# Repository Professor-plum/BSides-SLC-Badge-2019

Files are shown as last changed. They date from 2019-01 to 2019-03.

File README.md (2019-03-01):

# BSides-SLC-Badge-2019
source code, design files and artwork used in the BSides SLC 2019 badge

The following libraries were utilized in this project

https://github.com/rogerclarkmelbourne/Arduino_STM32
https://github.com/PaulStoffregen/SerialFlash
https://github.com/PaulStoffregen/XPT2046_Touchscreen

After installing these libraries, one edit needs to be made:

```
vim ~/Documents/Arduino/libraries/SerialFlash/SerialFlashChip.cpp
```

On line 161, change `SPIPORT.transfer(p, rdlen);` to be `SPIPORT.read(p, rdlen);`. I'm not sure if this is a bug in SerialFlash, or if SerialFlash was just designed to use a different STM32 library.

Now, in the Arduino IDE, you can open `src/BsidesSLCBig/BsidesSLCBig.ino`. Compile using the following board settings:

```
Board: "Generic STM32F103C Series"
Variant: "STM32F103CB (20k RAM, 128k Flash)"
```

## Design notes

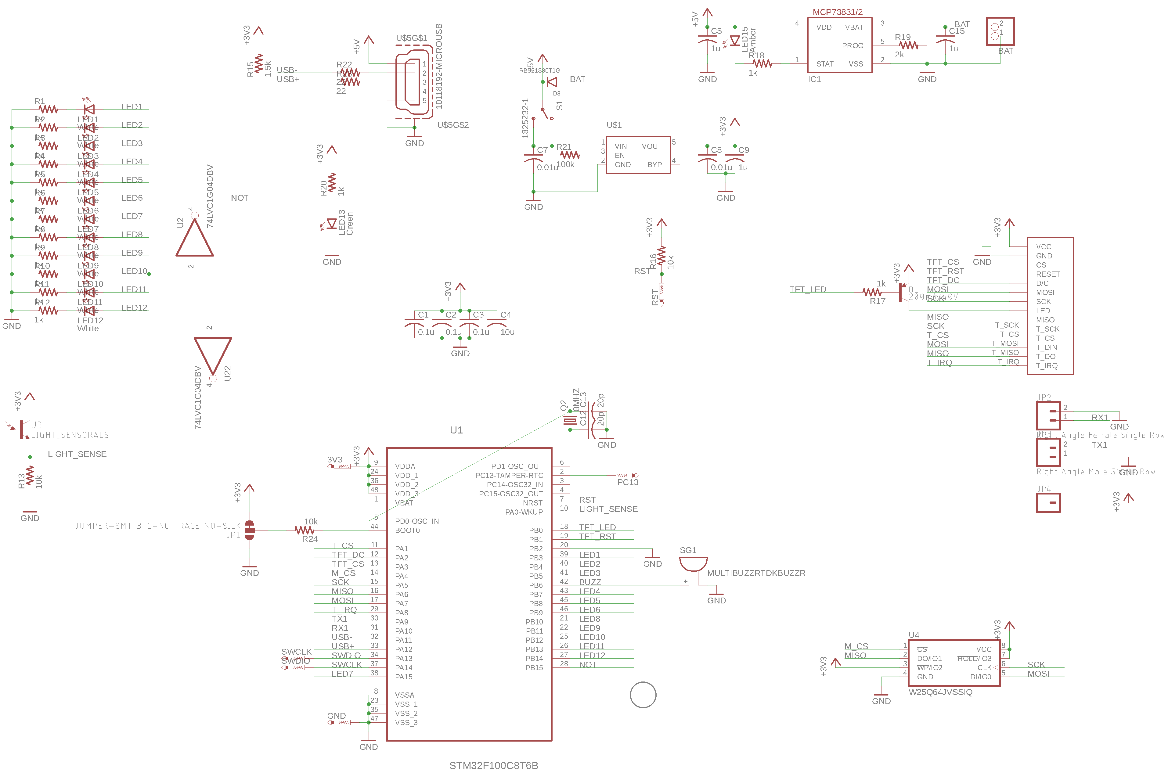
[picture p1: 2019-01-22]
eagle/Schematic.png

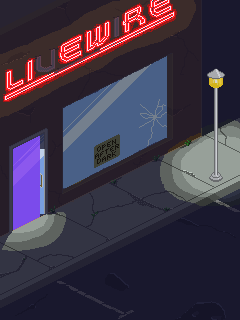
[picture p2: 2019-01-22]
img/nclub2.bmp

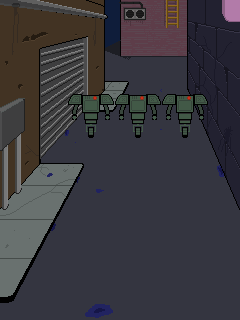
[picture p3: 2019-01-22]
img/street1.bmp

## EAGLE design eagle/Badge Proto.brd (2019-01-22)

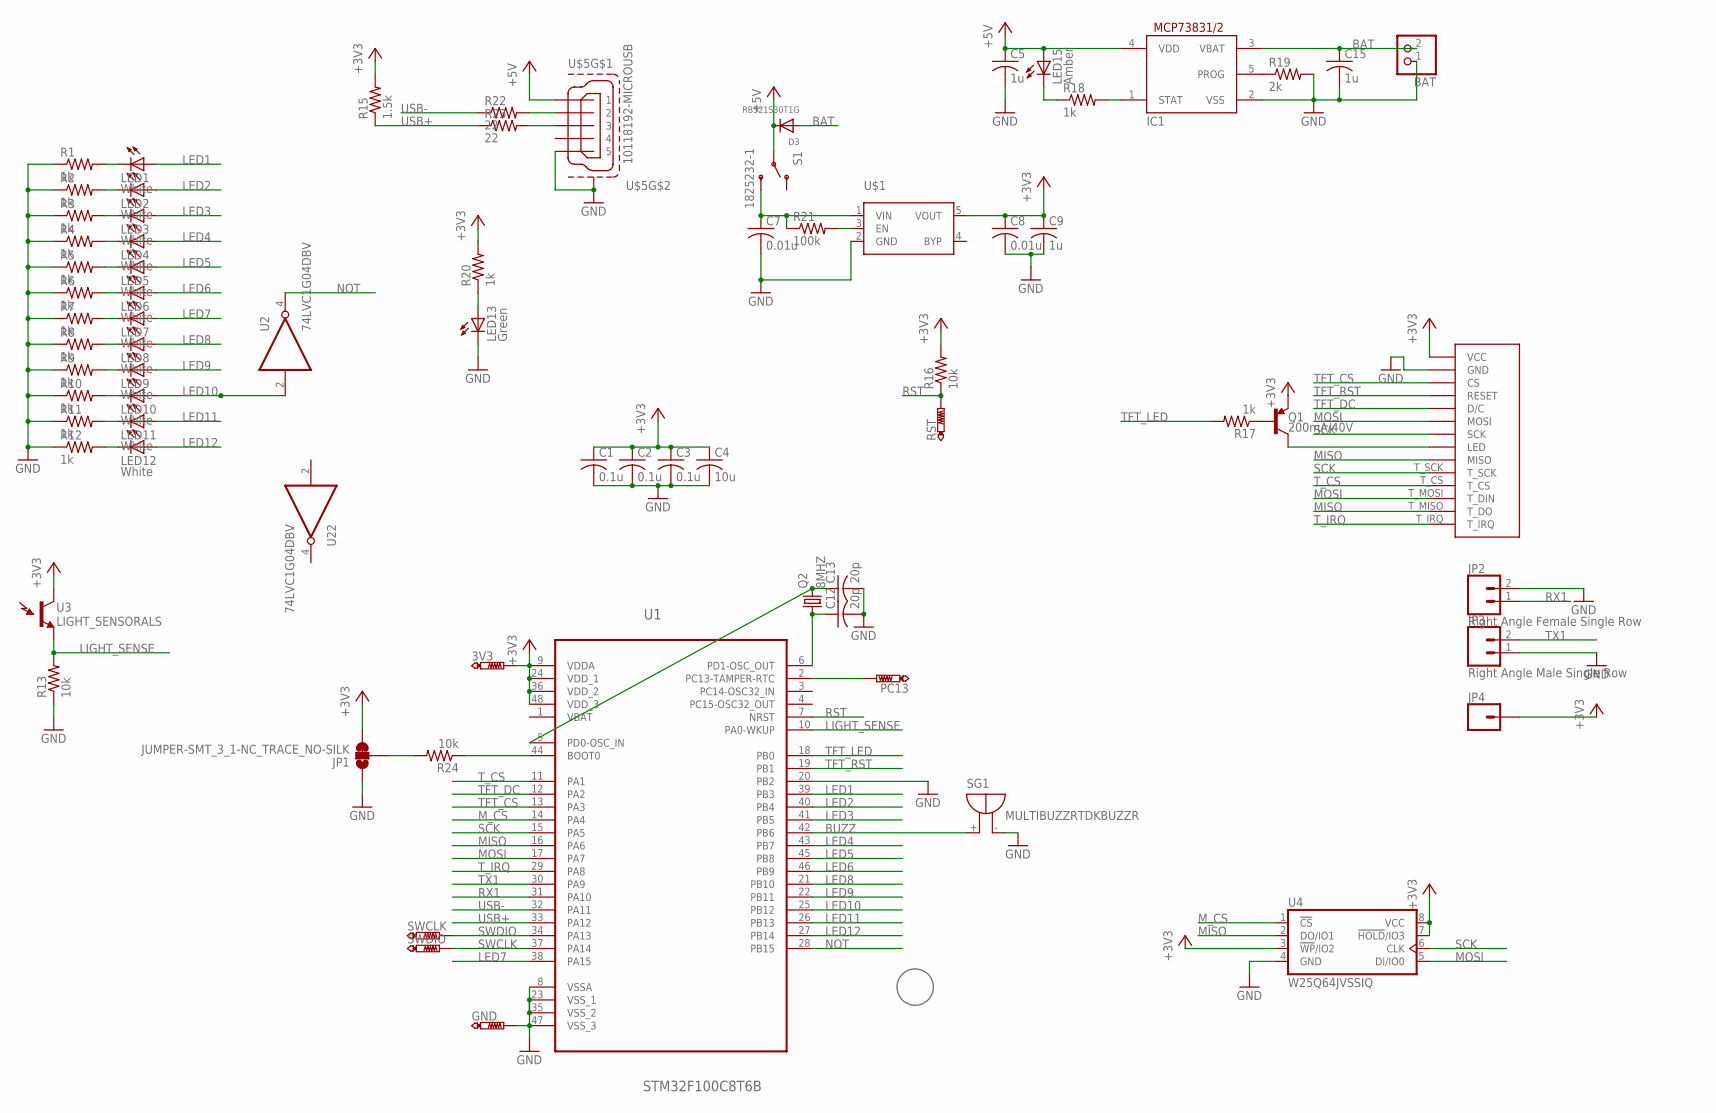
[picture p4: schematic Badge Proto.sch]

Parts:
3V3: PTR1TP15R; TP15R
BAT: JST_2PIN-THM-RA; JST-PH-2-THM-RA
C1, C2, C3: 0.1u; C0603K; MPN MC0603B104K160CT
C4: 10u; C0603K; MPN C1608X5R1A106K080AC
C5, C9, C15: 1u; C0603K; MPN C0603C104K8RACTU
C7, C8: 0.01u; C0603K
C12, C13: 20p; C0603K
D3: RB521S30T1G; SOD-523; MPN 1N4148WT.
GND: PTR1TP15R; TP15R
IC1: MCP73831/OT; SOT23-5L
J1: SPI_TFT_DISPLAY_TOUCH_NOSD; SPI_DISPLAY_TOUCH_NOSD
JP1: JUMPER-SMT_3_1-NC_TRACE_NO-SILK; SMT-JUMPER_3_1-NC_TRACE_NO-SILK
JP2: Right Angle Female Single Row; 1X02_RA_PTH_FEMALE
JP3: Right Angle Male Single Row; 1X02_RA_PTH_FEMALE
JP4: CONN_01PTH_NO_SILK_YES_STOP; 1X01_NO_SILK
LED1, LED2, LED3, LED4, LED5, LED6, LED7, LED8, LED9, LED10, LED11, LED12: White; SML0603
LED13: Green; SML0603
LED15: Amber; SML0603; MPN ASMT-RJ45-AQ502
PC13: PTR1TP15R; TP15R
Q1: 200mA/40V; SOT23-3
Q2: 8MHZ; HC49/S
R1, R2, R3, R4, R5, R6, R7, R8, R9, R10, R11, R12, R17, R18, R20: 1k; R0603; MPN ERJ-3GEYJ912V
R13, R16, R24: 10k; R0603; MPN RR0816P-103-D
R15: 1.5k; R0603; MPN MC0603SAF1501T5E
R19: 2k; R0603; MPN ERJ-6ENF2001V
R21: 100k; R0603; MPN MC0603SAF1003T5E
R22, R23: 22; R0603; MPN ERJ-3GEYJ220V
RST: PTR1TP15R; TP15R
S1: 1825232-1
SG1: MULTIBUZZRTDKBUZZR; BUZZRTDK
SWCLK: PTR1TP15R; TP15R
SWDIO: PTR1TP15R; TP15R
U1: STM32F100C8T6B; QFP50P900X900X160-48N
U2, U22: 74LVC1G04DBV; SOT23-5; MPN SN74LVC1G04DBVR
U3: LIGHT_SENSORALS; ALS-PT19
U4: W25Q64JVSSIQ; SO08-SS
U$1: SPX3819; SOT23-5
U$4: PLUM
U$5: 10118192-MICROUSB; MICROUSB-SMT; MPN 10118192-0002LF

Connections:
+3V3: 3V3.TP, C1.1, C2.1, C3.1, C4.1, C8.1, C9.1, J1.VCC, JP4.1, Q1.2 (E), R15.2, R16.2, R20.2, U1.9 (VDDA), U1.24 (VDD_1), U1.36 (VDD_2), U1.48 (VDD_3), U2.5 (VCC), U3.C (C1), U4.3 (!WP!/IO2), U4.7 (!HOLD!/IO3), U4.8 (VCC), U22.5 (VCC), U$1.5 (VOUT)
+5V: C5.1, D3.K (C), IC1.4 (VDD), LED15.A, S1.2, U$5.P$1 (1)
BAT: BAT.2, C15.1, D3.A, IC1.3 (VBAT)
BUZZ: SG1.+, U1.42 (PB6)
GND: BAT.1, C1.2, C2.2, C3.2, C4.2, C5.2, C7.2, C8.2, C9.2, C12.2, C13.2, C15.2, GND.TP, IC1.2 (VSS), J1.GND, JP1.1, JP2.2, JP3.1, LED13.C, R1.1, R2.1, R3.1, R4.1, R5.1, R6.1, R7.1, R8.1, R9.1, R10.1, R11.1, R12.1, R13.1, R19.2, SG1.-, U1.8 (VSSA), U1.20 (PB2), U1.23 (VSS_1), U1.35 (VSS_2), U1.47 (VSS_3), U2.3 (GND), U4.4 (GND), U22.3 (GND), U$1.2 (GND), U$5.P$5 (5), U$5.SHLD@0 (S4), U$5.SHLD@1 (S4), U$5.SHLD@2 (S4), U$5.SHLD@3 (S4), U$5.SHLD@4 (S4), U$5.SHLD@5 (S4)
LED1: LED1.A, U1.39 (PB3)
LED2: LED2.A, U1.40 (PB4)
LED3: LED3.A, U1.41 (PB5)
LED4: LED4.A, U1.43 (PB7)
LED5: LED5.A, U1.45 (PB8)
LED6: LED6.A, U1.46 (PB9)
LED7: LED7.A, U1.38 (PA15)
LED8: LED8.A, U1.21 (PB10)
LED9: LED9.A, U1.22 (PB11)
LED10: LED10.A, U1.25 (PB12), U2.2 (I)
LED11: LED11.A, U1.26 (PB13)
LED12: LED12.A, U1.27 (PB14)
LIGHT_SENSE: R13.2, U1.10 (PA0-WKUP), U3.E (E1)
MISO: J1.MISO, J1.T_MISO (T_DO), U1.16 (PA6), U4.2 (DO/IO1)
MOSI: J1.MOSI, J1.T_MOSI (T_DIN), U1.17 (PA7), U4.5 (DI/IO0)
M_CS: U1.14 (PA4), U4.1 (!CS!)
unnamed: LED1.C, R1.2
unnamed: LED2.C, R2.2
unnamed: LED3.C, R3.2
unnamed: LED4.C, R4.2
unnamed: LED5.C, R5.2
unnamed: LED6.C, R6.2
unnamed: LED7.C, R7.2
unnamed: LED8.C, R8.2
unnamed: LED9.C, R9.2
unnamed: R22.2, U$5.P$2 (2)
unnamed: R23.2, U$5.P$3 (3)
unnamed: R21.2, U$1.3 (EN)
unnamed: Q1.1 (B), R17.1
unnamed: IC1.5 (PROG), R19.1
unnamed: JP1.2, R24.2
unnamed: C12.1, Q2.1, U1.6 (PD1-OSC_OUT)
unnamed: C13.1, Q2.2, U1.5 (PD0-OSC_IN)
unnamed: LED15.C, R18.1
unnamed: IC1.1 (STAT), R18.2
unnamed: LED10.C, R10.2
unnamed: LED11.C, R11.2
unnamed: LED12.C, R12.2
unnamed: LED13.A, R20.1
unnamed: C7.1, R21.1, S1.1, U$1.1 (VIN)
unnamed: R24.1, U1.44 (BOOT0)
unnamed: PC13.TP, U1.2 (PC13-TAMPER-RTC)
NOT: U1.28 (PB15), U2.4 (O)
NS1: J1.LED, Q1.3 (C)
RST: R16.1, RST.TP, U1.7 (NRST)
RX1: JP2.1, U1.31 (PA10)
SCK: J1.SCK, J1.T_SCK, U1.15 (PA5), U4.6 (CLK)
SWCLK: SWDIO.TP, U1.37 (PA14)
SWDIO: SWCLK.TP, U1.34 (PA13)
TFT_CS: J1.CS, U1.13 (PA3)
TFT_DC: J1.D/C, U1.12 (PA2)
TFT_LED: R17.2, U1.18 (PB0)
TFT_RST: J1.RESET, U1.19 (PB1)
TX1: JP3.2, U1.30 (PA9)
T_CS: J1.T_CS, U1.11 (PA1)
T_IRQ: J1.T_IRQ, U1.29 (PA8)
USB+: R15.1, R23.1, U1.33 (PA12)
USB-: R22.1, U1.32 (PA11)
VBAT: U1.1 (VBAT)

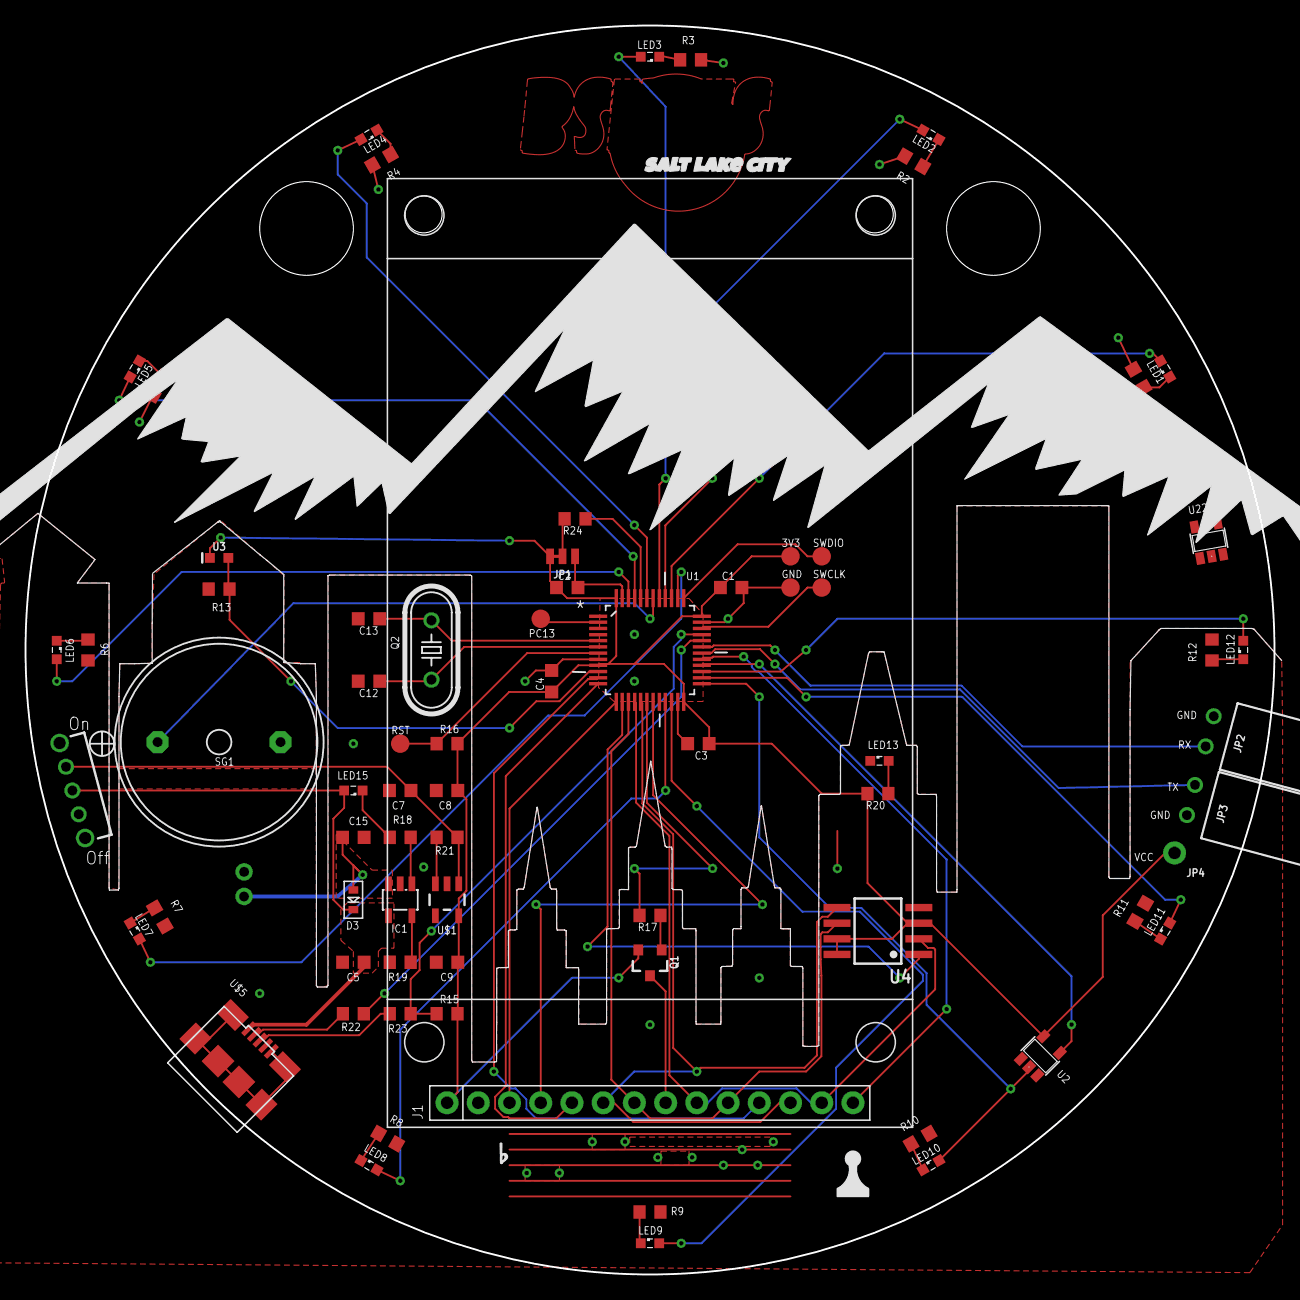
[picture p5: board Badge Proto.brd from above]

Board: 2 copper layers, 101.6 x 101.6 mm, 74 parts (1 on the bottom side), 63 nets.

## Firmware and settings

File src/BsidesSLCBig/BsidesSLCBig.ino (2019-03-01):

#include <SPI.h>
#include "Adafruit_ILI9341_STM_Ext_Sleep.h"
#include <XPT2046_Touchscreen.h>
#include "LedWheel.h"
#include <EEPROM.h>

#include "Room.h"
#include "FlashReader.h"

#include "AlleyRoom.h"
#include "DialRoom.h"
#include "MarketRoom.h"
#include "GameRoom.h"
#include "MainFrameRoom.h"
#include "TVRoom.h"
#include "StreetRoom.h"
#include "ArcadeRoom.h"
#include "TowerRoom.h"
#include "KeypadRoom.h"
#include "PuzzleRoom.h"
#include "NightClub.h"
#include "DJRoom.h"
#include "PanelRoom.h"
#include "SplashRoom.h"
#include "EndRoom.h"


#define TFT_DC    PA2
#define TFT_RST   PB1 
#define TFT_CS    PA3
#define TFT_LED   PB0

#define SF_CS     PA4

#define T_CS      PA1
#define T_IRQ     PA8

#define BUZZ      PB6 

#define MAX_LIGHT 60000

Adafruit_ILI9341_STM_Ext_Sleep tft = Adafruit_ILI9341_STM_Ext_Sleep(TFT_CS, TFT_DC, TFT_RST);
XPT2046_Touchscreen ts(T_CS, T_IRQ);

uint16_t TS_MINX    = 200;
uint16_t TS_MINY    = 150;
uint16_t TS_MAXX    = 3800;
uint16_t TS_MAXY    = 3700;

Room *cur;

void calibrate();
bool ask();

const char* peermsg[] = {
  "1-AGILE",
  "2-DRIVE",
  "3-MIGHT",
  "4-HEART",
  "5-VIGOR"
};

void setup() {
  Serial.begin(19200);
  
  pinMode(PA10, INPUT_PULLUP);
  //Serial1.begin(9600);
  
  FR.begin(SF_CS);
  
  tft.begin();
  //tft.setRotation(1);
  tft.fillScreen(ILI9341_BLUE);
  
  ts.begin();
  ts.setRotation(3);



  pinMode(LIGHT, INPUT_ANALOG);
  randomSeed(analogRead(LIGHT)); 
  
  EEPROM.init();
  
  peer_id = EEPROM.read(10);
  if ((peer_id <=0) || (peer_id > 5)) {
    peer_id = (rand() % 5) +1;
    //Serial.print("Invalid peer_id, Resetting to ");Serial.println(peer_id);
    EEPROM.write(10, peer_id);
    EEPROM.write(50, TS_MINX);
    EEPROM.write(52, TS_MINY);
    EEPROM.write(54, TS_MAXX);
    EEPROM.write(56, TS_MAXY);
  }
  else {
    TS_MINX = EEPROM.read(50);
    TS_MINY = EEPROM.read(52);
    TS_MAXX = EEPROM.read(54);
    TS_MAXY = EEPROM.read(56);
  }
  for (int i=0; i< 5; i++) {
    if (EEPROM.read(40+i) == 0xcc)
      peers[i] = true;
  }




  for (int i=0; i<12; ++i)
    pinMode(ledMap[i], OUTPUT);

  for (int i=11; i>=0; --i) {
    digitalWrite(ledMap[i], HIGH);
    delay(50);
    digitalWrite(ledMap[i], LOW);
  }

  wheel_init();
  wavInit();

  pinMode(NOTPIN, INPUT);

  cur =  new SplashRoom(); 
  cur->refresh(&tft, 0);

}

uint32_t last=0;
uint32_t lastDraw=0;
int backlight = MAX_LIGHT;
bool touched = false;
bool sleeping = false;
TS_Point p;
uint32_t lastSerial = 0;

void loop() {
  uint32_t now=millis();
  uint32_t dt = now - last;
  last = now;

  if (sleeping) {
      if (ts.touched()) {
        SerialFlash.wakeup();
        SPI.beginTransaction(SPISettings(48000000, MSBFIRST, SPI_MODE0, DATA_SIZE_16BIT));
        tft.exitSleepMode();
        sleeping = false;
      }
      return; //early out
    }

  wavCheckBuff();

  if (true){//(now - lastDraw > 100) { //shoot for 10 fps, may not achieve this
    SPI.beginTransaction(SPISettings(48000000, MSBFIRST, SPI_MODE0, DATA_SIZE_16BIT));
    roomID id = cur->update(&tft, now);
    lastDraw = now;
    if (id == R_CONFIGURE) {
      calibrate();
      if (ask("Do you want to reset progress?")) {
        for (int i=0; i<12; ++i)
          EEPROM.update(20+i, 0);
        EEPROM.update(10, 0xff);
        for (int i=0; i<6; ++i)
          EEPROM.update(40+i, 0);
      }
      /*if (ask("Do you want to reprogram the flash?"))
        if (ask("Are you sure, this will wipe all data?!"))
          WriteFlash(&tft);*/
      nvic_sys_reset();
    }
    else if (id != R_NOCHANGE) {
      delete cur;
      switch(id) {
        case R_ALLEY:
          cur = new AlleyRoom();
          break;
        case R_TV:
          cur = new TVRoom();
          break;
        case R_MARKET:
          cur = new MarketRoom();
          break;
        case R_DIAL:
          cur = new DialRoom();
          break;
        case R_MAINFRAME:
          cur = new MainFrameRoom();
          break;
        case R_STREET:
          cur= new StreetRoom();
          break;
        case R_NIGHTCLUB:
          cur= new NightClub();
          break;
        case R_ARCADE:
          cur = new ArcadeRoom();
          break;
        case R_GAME:
          cur = new GameRoom();
          break;
        case R_DJ:
          cur = new DJRoom(); 
          break;
        case R_PUZZLE:
          cur= new PuzzleRoom();
          break;
        case R_KEYPAD:
          cur = new KeypadRoom();
          break;
        case R_TOWER:
          cur = new TowerRoom();
          break;
        case R_PANEL:
          cur = new PanelRoom();
          break;
        case R_SPLASH:
          cur = new SplashRoom();
          break;
        case R_END:
          cur = new EndRoom();
          break;
      }
      SPI.beginTransaction(SPISettings(48000000, MSBFIRST, SPI_MODE0, DATA_SIZE_16BIT));
      tft.fillScreen(ILI9341_BLACK);
      cur->refresh(&tft, now);
    }
  }

  wavCheckBuff();
    
  if (ts.touched()) {
    p = ts.getPoint();
    backlight = MAX_LIGHT;
    digitalWrite(TFT_LED, LOW);
    int t = p.x;
    p.x = p.y;
    p.y = t;
    p.x = map(p.x, TS_MINX, TS_MAXX, 0, 240);
    p.y = map(p.y, TS_MINY, TS_MAXY, 0, 320); 
    if (touched)
      cur->touchMove(p.x, p.y);
    else {
      touched = true;
      cur->touchDown(p.x, p.y);
    }

  }
  else if (touched) {
    touched = false;
    cur->touchUp(p.x, p.y);
  }

  if (lastSerial + 2000 < now) {
    Serial.println(peermsg[peer_id-1]);
    lastSerial = now;
  }
  while (Serial.available() >= 7) {
    char rin[8] = {0};
    rin[0] = Serial.read();
    if ((rin[0] >'0') && (rin[0] < '6')) {
      for (int i=1; i<7; ++i) {
        rin[i] = Serial.read();
      }
      for (int i=0; i<5; ++i) {
        if (memcmp(rin, peermsg[i], 7)==0) {
          wavPlay("pair.wav");
          if (!peers[i]) {
            peers[i] = true;
            EEPROM.update(40+i, 0xcc);
          }
        }
      }
    }
  }

  if (backlight > 0) {
    analogWrite(TFT_LED, max(0, 255-(backlight/5)));
    backlight-=dt;
  }
  else { //Time to sleep
    SerialFlash.sleep();
    SPI.beginTransaction(SPISettings(48000000, MSBFIRST, SPI_MODE0, DATA_SIZE_16BIT));
    tft.enterSleepMode();
    sleeping = true;
    digitalWrite(TFT_LED, HIGH);
  }

}

void calibrate() {
  int poses[2] = {0,0};
  digitalWrite(TFT_LED, HIGH);
  SPI.beginTransaction(SPISettings(48000000, MSBFIRST, SPI_MODE0, DATA_SIZE_16BIT));
  tft.fillScreen(ILI9341_RED);
  tft.setTextSize(1);
  tft.setTextColor(ILI9341_BLACK);
  tft.setCursor(85, 120);
  tft.print("With pen,");
  tft.setCursor(50, 130);
  tft.print("touch top left");
  tft.setCursor(40, 140);
  tft.print("corner of screen");
  tft.drawFastHLine(1, 0, 5, ILI9341_BLACK);
  tft.drawFastVLine(0, 1, 5, ILI9341_BLACK);
  delay(500);

  for (int i=0; i< 10; ++i) {
    while (!ts.touched()) delay(50);
    TS_Point p = ts.getPoint();

    poses[1] += p.x;
    poses[0] += p.y;
  }
  TS_MINX = poses[0]/10;
  TS_MINY = poses[1]/10;
  poses[0] = poses[1] = 0;

  while (ts.touched()) delay(50);

  SPI.beginTransaction(SPISettings(48000000, MSBFIRST, SPI_MODE0, DATA_SIZE_16BIT));
  tft.fillScreen(ILI9341_GREEN);
  tft.setCursor(85, 120);
  tft.print("With pen,");
  tft.setCursor(20, 130);
  tft.print("touch bottom right");
  tft.setCursor(40, 140);
  tft.print("corner of screen");
  tft.drawFastHLine(234, 319, 5, ILI9341_BLACK);
  tft.drawFastVLine(239, 314, 5, ILI9341_BLACK);  
  delay(1000);

  for (int i=0; i< 10; ++i) {
    while (!ts.touched()) delay(50);
    TS_Point p = ts.getPoint();

    poses[1] += p.x;
    poses[0] += p.y;
  }
  TS_MAXX = poses[0]/10;
  TS_MAXY = poses[1]/10; 

  EEPROM.update(50, TS_MINX);
  EEPROM.update(52, TS_MINY);
  EEPROM.update(54, TS_MAXX);
  EEPROM.update(56, TS_MAXY);

  /*Serial.println(TS_MINX);
  Serial.println(TS_MINY);
  Serial.println(TS_MAXX);
  Serial.println(TS_MAXY);*/

  SPI.beginTransaction(SPISettings(48000000, MSBFIRST, SPI_MODE0, DATA_SIZE_16BIT));
  tft.setTextSize(1);
}

bool ask(const char* msg) {
  SPI.beginTransaction(SPISettings(48000000, MSBFIRST, SPI_MODE0, DATA_SIZE_16BIT));
  tft.fillRoundRect(2,100, 236, 100, 5, ILI9341_BLUE);
  tft.setTextColor(ILI9341_WHITE);
  tft.setCursor(10, 120);
  tft.setTextSize(1);
  tft.print(msg);
  tft.fillRoundRect(30, 170, 60, 20, 3, ILI9341_NAVY);
  tft.fillRoundRect(150, 170, 60, 20, 3, ILI9341_NAVY);
  tft.setCursor(50, 175);
  tft.print("Yes");
  tft.setCursor(170, 175);
  tft.print("No");
  delay(500);

  while (true) {
    if (ts.touched()) {
      TS_Point p = ts.getPoint();
      int t = p.x;
      p.x = p.y;
      p.y = t;
      p.x = map(p.x, TS_MINX, TS_MAXX, 0, 240);
      p.y = map(p.y, TS_MINY, TS_MAXY, 0, 320); 
      if ((p.y > 170) && (p.y < 190)){
        if ((p.x>30) && (p.x<90)) return true;
        if ((p.x>150) && (p.x<210)) return false;
      }
    }
    delay(50);
  }
  SPI.beginTransaction(SPISettings(48000000, MSBFIRST, SPI_MODE0, DATA_SIZE_16BIT));
}

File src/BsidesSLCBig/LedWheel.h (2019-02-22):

#ifndef LEDWHEEL
#define LEDWHEEL
#include <Arduino.h>

#define ledTimer	Timer2
const char ledMap[12] = {PB3, PB4, PB5, PB7, PB8, PB9, PA15, PB10, PB11, PB12, PB13, PB14};

void wheel_init();
void wheel_set(int id, bool on);
bool wheel_get(int id);
bool wheel_complete();

#endif

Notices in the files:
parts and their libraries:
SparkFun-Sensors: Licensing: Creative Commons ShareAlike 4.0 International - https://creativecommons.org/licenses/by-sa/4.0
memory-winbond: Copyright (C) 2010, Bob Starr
